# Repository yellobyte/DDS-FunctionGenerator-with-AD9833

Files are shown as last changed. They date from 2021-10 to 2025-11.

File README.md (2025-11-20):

# DDS Function Generator with AD9833 module #

While doing some work on Audio Amplifiers and Light Organs in 2016 I needed a simple (and not necessarily absolutely precise) **Function Generator** to generate sinus signals in the frequency range of 10Hz...30kHz and voltage levels of about 0.7...1Vrms. All devices I needed to test had input impedances in the range of ~2kOhm...20kOhm. 
  
Unfortunately I didn't call a function generator my own. So in order to have some additional fun, putting together one by myself instead of buying one on the internet was the only option. I ended up with a device able to generate output signals with the following specifications:

 - **Sinus/Triangle, amplitude 0.01 to 6.00 Vpp, frequency 1Hz to 500kHz**
 - **TTL, amplitude 5 Vpp, frequency 1Hz to 5.0 MHz**
 
 Switching waveform, output level and frequency is done with 2 front panel knobs: a pushbutton switch labelled "Select" and a simple rotary encoder with push switch labelled "Modify". The display is a standard 16x2 LCD (HD44780) having a small I2C-LCD adapter module (PCF8574 I/O expander) mounted piggyback.

All components were put into an enclosure UM 52011-L from [Bopla](https://www.bopla.de/en/enclosure-technology/product/ultramas/enclosure-with-air-vents/um-52011-l.html) which had exactly the size needed.
  
### Front side with 2 controls, 16x2 LCD display and BNC output socket: ###
  
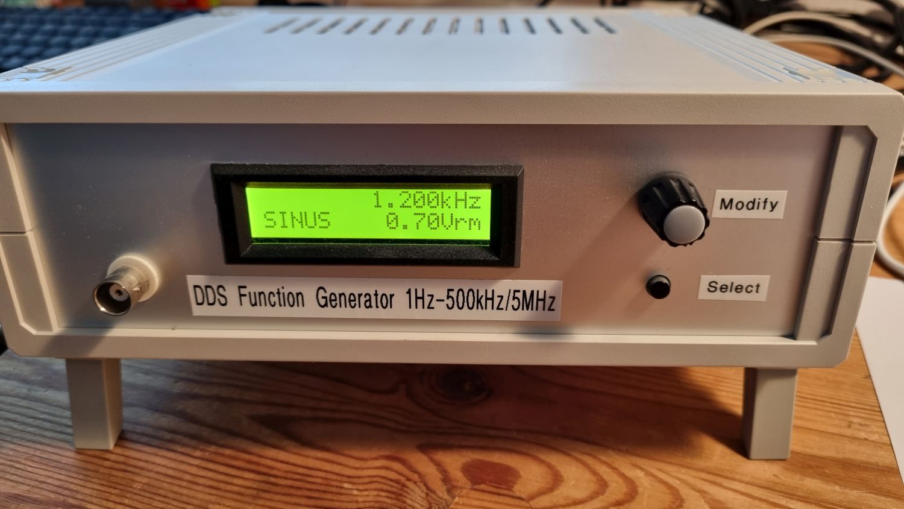
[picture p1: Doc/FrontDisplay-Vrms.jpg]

  
The two controls allow to change signal [waveform](https://github.com/yellobyte/DDS-FunctionGenerator-with-AD9833/raw/main/Doc/SettingWaveform.mp4), output [level](https://github.com/yellobyte/DDS-FunctionGenerator-with-AD9833/raw/main/Doc/SettingLevel+SwitchingBetweenVppVrms.mp4) (Vpp resp. Vrms for sinus/triangle) and [frequency](https://github.com/yellobyte/DDS-FunctionGenerator-with-AD9833/raw/main/Doc/SettingFrequency.mp4) very quickly. Have a look at folder [**Doc**](https://github.com/yellobyte/DDS-FunctionGenerator-with-AD9833/blob/main/Doc) to find more details. 
  
## General technical info ##

The analog part of the circuitry is shielded in tin plate (an old coffee tin proved ideal for this purpose, you will recognize my favorite Italian coffee brand) to keep the output signal as clear as possible and reduce EMI. 
  
The settings for waveform/level/frequency get stored in EEPROM of the Atmega168A and therefore stay permanent even after switching the device off/on.

By default, turning the encoder knob will change the output signal immediately. For example, changing the output level from 0.5Vpp up to 6.00Vpp requires a few full turns of the knob and therefore will take a few seconds. Means the output level will rise steadily.
  
However, sometimes, when testing the automatic gain control (AGC) of audio input stages for example, it requires a signal that rises instantaneously . No problem! Switch off the device and have the encoder knob pressed for two seconds while switching power back on. After that, changing a single setting (waveform, level or frequency) on the display will not affect the output signal. Only after pressing the knob shortly (<0.5s) will the new setting appear at the output.
    
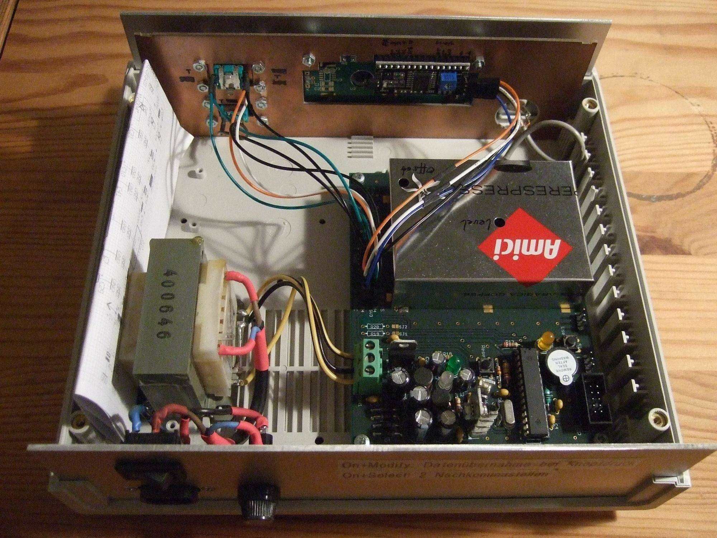
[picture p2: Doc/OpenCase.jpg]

  
### Some circuit details ###
    
The DDS module (available for only a few dollars on Ebay/Ali/etc.) uses a sophisticated programmable waveform generator IC [AD9833](https://www.analog.com/en/products/ad9833.html) with 0...12.5MHz output frequency rate. 
  
Unfortunately the output pin of the AD9833 chip on the small **DDS module** shipped from Asia was galvanically isolated from the modules output pin (due to C8/C9). The quickest remedy was to bridge one of the two capacitors with a short wire, as you can see on the [**board**](https://github.com/yellobyte/DDS-FunctionGenerator-with-AD9833/raw/main/Doc/Board_V1.0_top.jpg) or below in the modules schematic. Apart from that the module was perfect for the task.

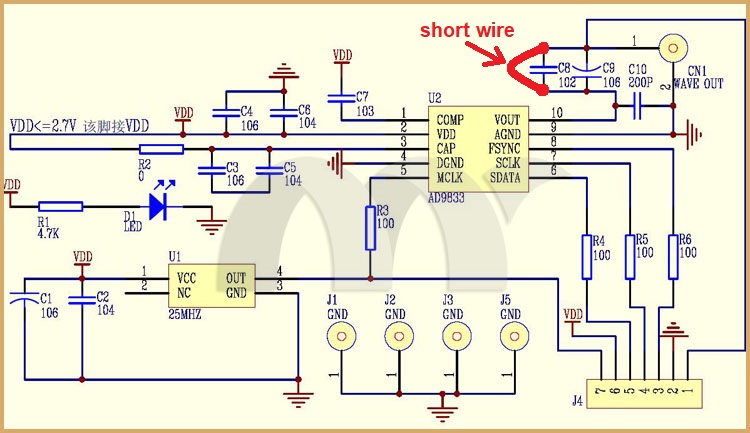
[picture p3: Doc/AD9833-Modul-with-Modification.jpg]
  

The AD9833 is written to via SPI interface. The internet provides ready to use libraries for it but I decided to use some small, quick and dirty code for only two features are needed: setting frequency & waveform.
  
The output signal of the AD9833 is unipolar and has a constant amplitude  of +38mV...+650mV over the full frequency range. The combination of Opamps IC3 + IC5 converts it to a bipolar, symmetrical signal with constant amplitude +/- 3.0V (6Vpp).  

The combination DAC1/IC6/IC7 is then used to attenuate this signal to the desired output level. The DAC IC [AD5452](https://www.analog.com/en/products/ad5452.html) contains a 12-bit R-2R-ladder and simply sets the amplification factor (better to say attenuation factor) of the combination IC6 (Opamp) + IC7 (unity gain buffer). To set the output level the selected value (0.01...6.00Vpp resp. its equivalent in Vrms) gets translated into a 12-bit value (range 0...4095) and then written to the DAC via SPI bus.

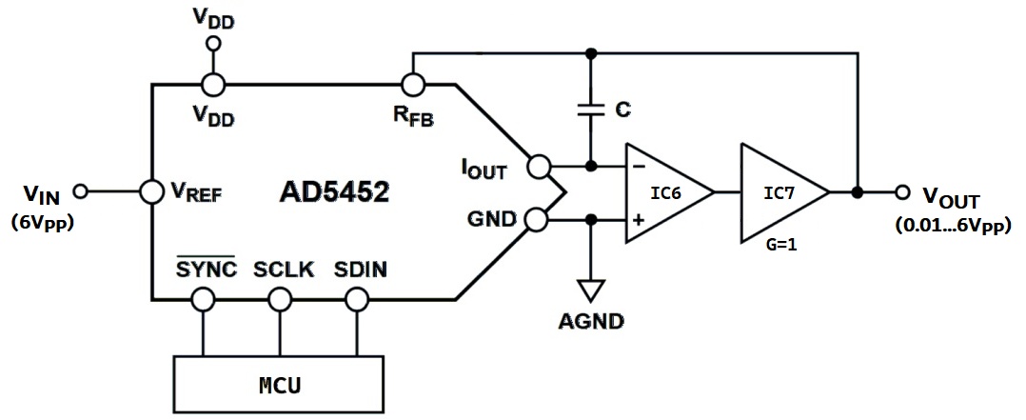
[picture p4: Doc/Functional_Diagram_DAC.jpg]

  
The [LMH6321](https://www.ti.com/product/LMH6321) (IC7) acts as output driver/buffer with gain=1 (unity gain) and features an  "adjustable current limit". Resistor R16 sets this limit to roughly 110mA for thermal protection in case of a short at the BNC output socket.
  
Capacitors C20/C22/C38 are not populated because the Opamp [NE5534](https://www.ti.com/product/NE5534) (IC6) showed sufficient results without them. In case you want to increase the maximum analog output frequency and try different Opamps for best results you might need them.

The two 100 Ohm resistors R9/R14 in parallel at the IC7 driver output were designed into the schematic and soldered on the board but shorted with wire in the end because the device will solely get connected to audio devices with a few 1..10kOhm input impedance and only generates audio resp. low analog frequency signals anyway. Means it will never produce RF signals, see low impedance loads, mismatches, reflections and other effects of RF hell. BTW: Having those two resistors in parallel and feeding devices with very low input impedance, e.g. 50 Ohm, would in this case halve the usable signal amplitude and subsequently force you to correct the displayed signal level on LCD, etc. Things would get complicated. 
  
Therefore wiring the IC7 driver output directly to CON2 (connected to BNC output socket) gives the function generator a very low output impedance and is appropriate under these circumstances. 

The rotary encoders two outer pins go to IMPULS-A/IMPULS-B and the middle one to ground GND. It's two switch pins go to IMPULS-SW and GND. The two pins of the separate "Select" switch go to SELECT-SW and GND on the board.  

The four pins of socket "LCD 16x2" go to the matching pins on the small **I2C-LCD board** that is mounted piggyback on the 16x2 LCD front display.
  
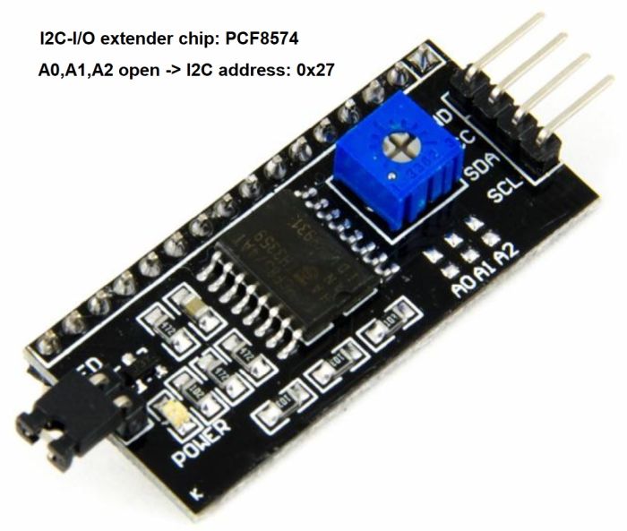
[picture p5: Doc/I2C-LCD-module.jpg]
  

The logic gate IC8D is a low-power-Schottky Schmitt-Trigger-Inverter [74LS14](https://www.ti.com/product/SN74LS14) which acts as buffer between DDS chip and BNC output socket when a TTL output signal is selected. Firstly, its TTL signal is slightly better than the one generated by the AD9833 and secondly, a permanent short at the output would only destroy this socketed, easy replacable and inexpensive chip and not the tiny DDS chip (AD9833 in a MSOP package) soldered on the DDS module.
  
The whole device is powered by a standard 230V(prim)/2x6V(sec)/12VA transformer attached to CON1. Two jellybean voltage regulator ICs (IC2/7805 and IC4/7905) provide the needed positive/negative voltages.
  
The firmware for the device was done with VSCode/PlatformIO and is located in folder [**Software**](https://github.com/yellobyte/DDS-FunctionGenerator-with-AD9833/blob/main/Software) together with all needed fuse settings. For programming the Atmega168A I used this in-circuit [**Programmer**](https://github.com/yellobyte/USB-Atmel-In-Circuit-Programmer), connected to the 10-pin ISP socket.
  
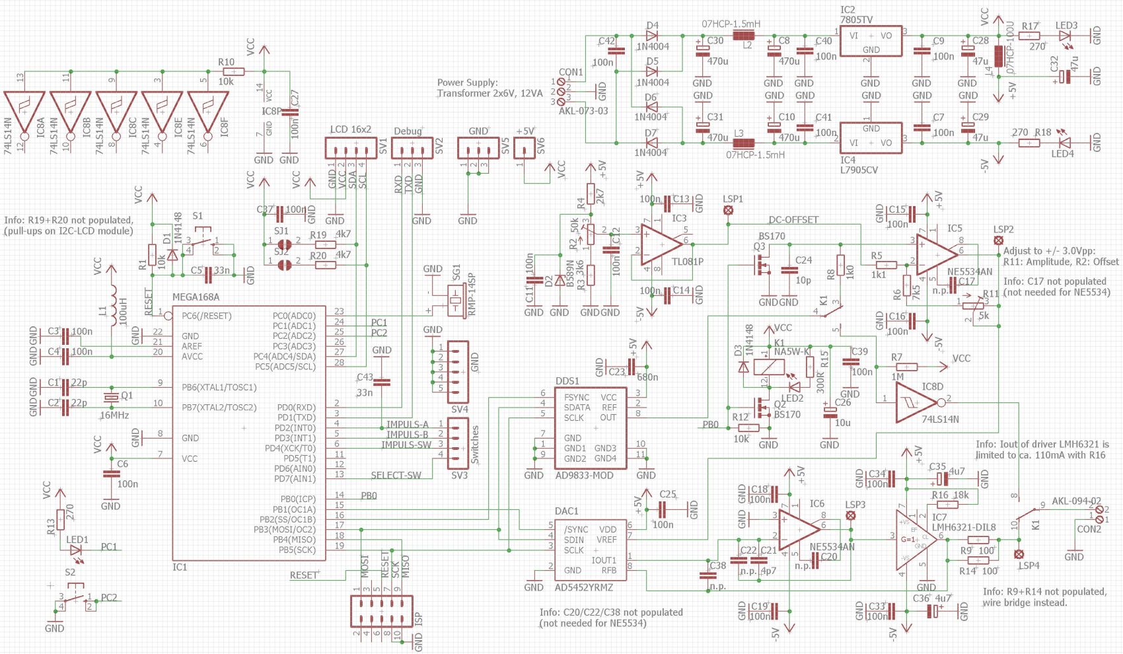
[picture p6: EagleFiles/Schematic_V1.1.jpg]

  
### Adjusting procedure ###

For properly adjusting the analog part an oscilloscope connected to output (BNC socket) is recommended/needed. Trimmer R11 sets the maximum amplitude and trimmer R2 adjusts the offset for getting a symmetrical signal.
  
First set the output signal to Sinus, 1.000kHz and 6.00Vpp using the knobs. Then adjust the analog output signal with the two trimmers as shown below. If your osci can display Cmean, have an eye on it. Try to get it to +/-0V as close as possible for a nice symmetrical output signal without offset.

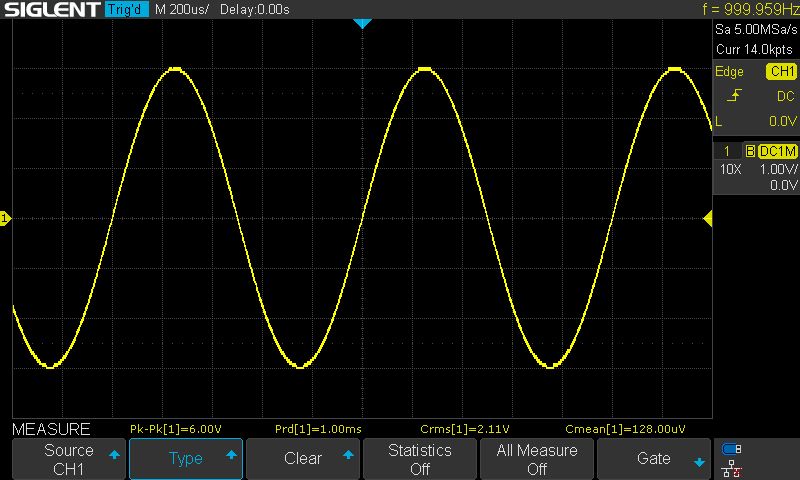
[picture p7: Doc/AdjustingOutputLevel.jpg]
 

## Eagle Schematic and PCB Files ##

All relevant Eagle files (schematic, board and Gerber production files Rev 1.1) are located in folder [**EagleFiles**](https://github.com/yellobyte/DDS-FunctionGenerator-with-AD9833/blob/main/EagleFiles). The necessary Gerber files for production are zipped into file "FG with AD9833.zip".  

The pictures in folder [**Doc**](https://github.com/yellobyte/DDS-FunctionGenerator-with-AD9833/blob/main/Doc) still show board revision 1.0.   Revision 1.1 is almost identical and contains only cosmetic changes.

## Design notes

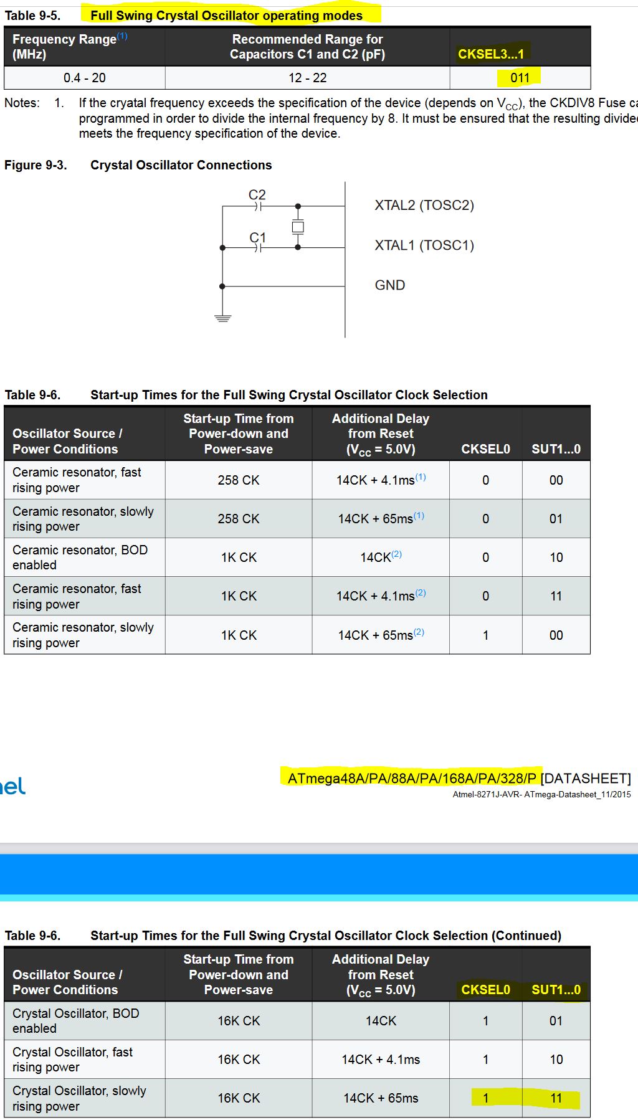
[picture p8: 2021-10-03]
Software/Low-Fuse-Spec2.JPG

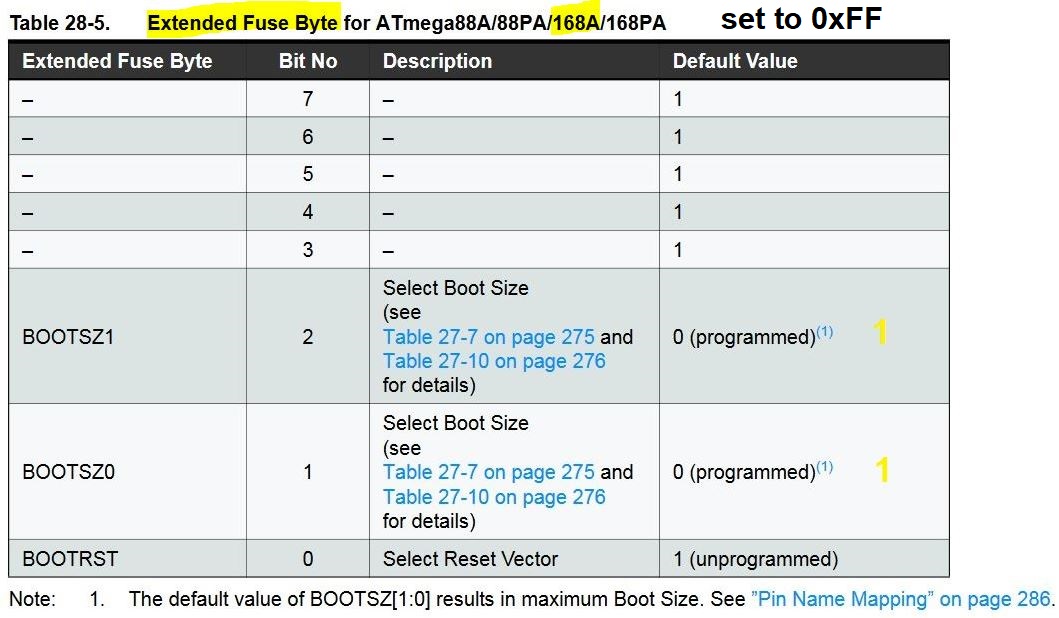
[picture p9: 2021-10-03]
Software/Extended-Fuse-Spec1.JPG

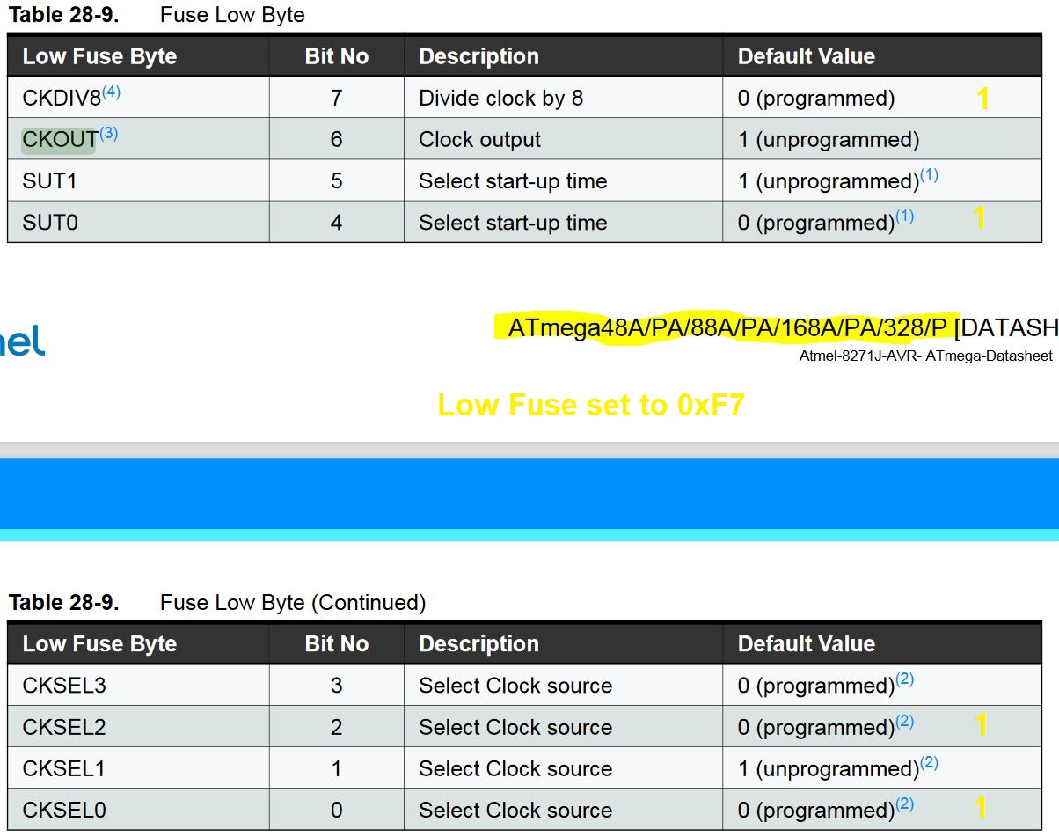
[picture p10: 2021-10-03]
Software/Low-Fuse-Spec1.JPG

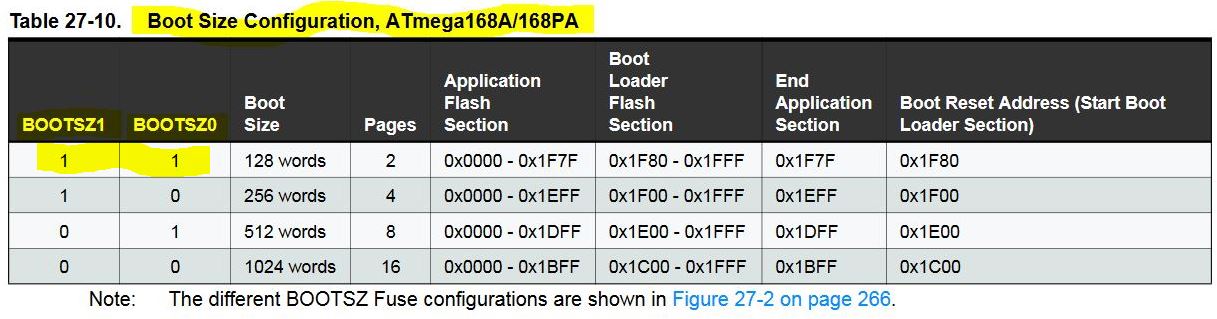
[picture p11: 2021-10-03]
Software/Extended-Fuse-Spec2.JPG

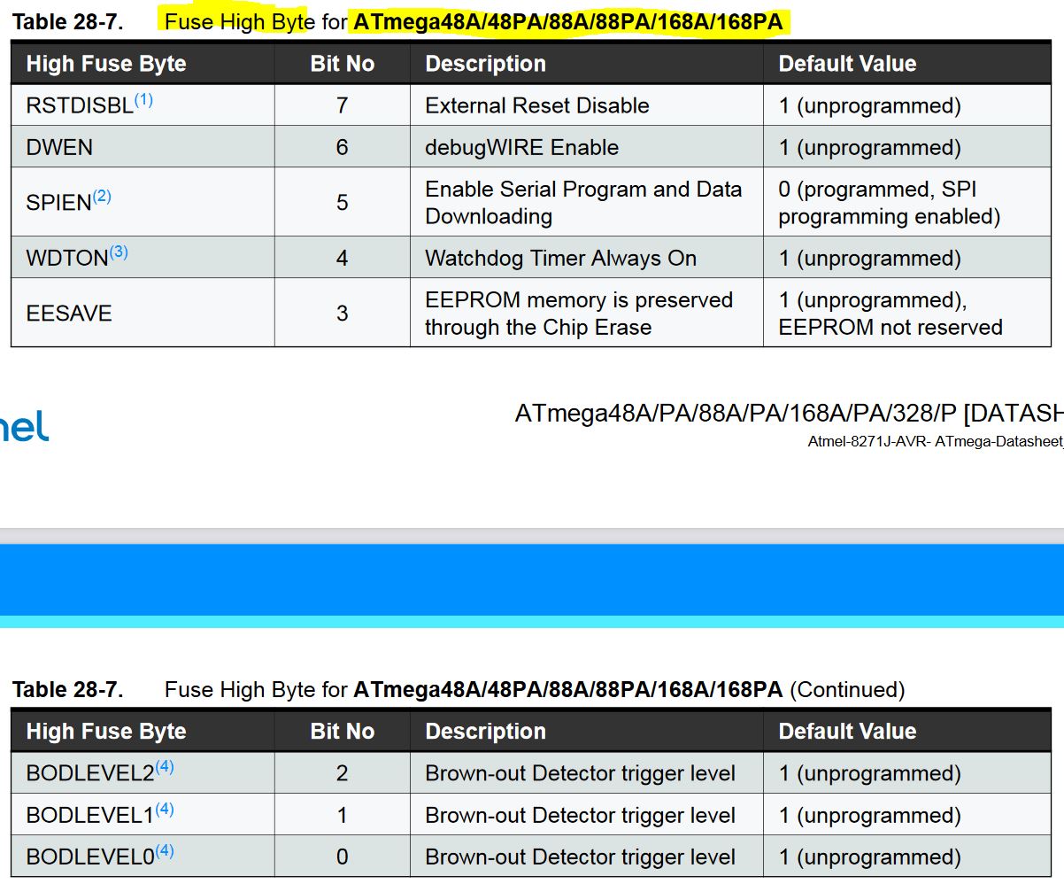
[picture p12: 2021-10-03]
Software/High-Fuse-Spec.JPG

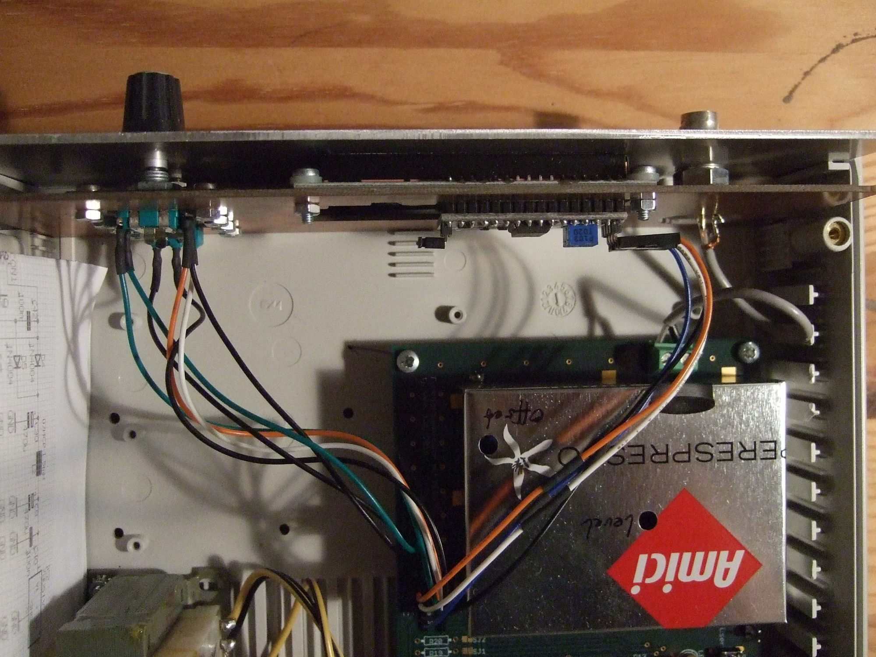
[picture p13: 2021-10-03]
Doc/FrontModule.JPG

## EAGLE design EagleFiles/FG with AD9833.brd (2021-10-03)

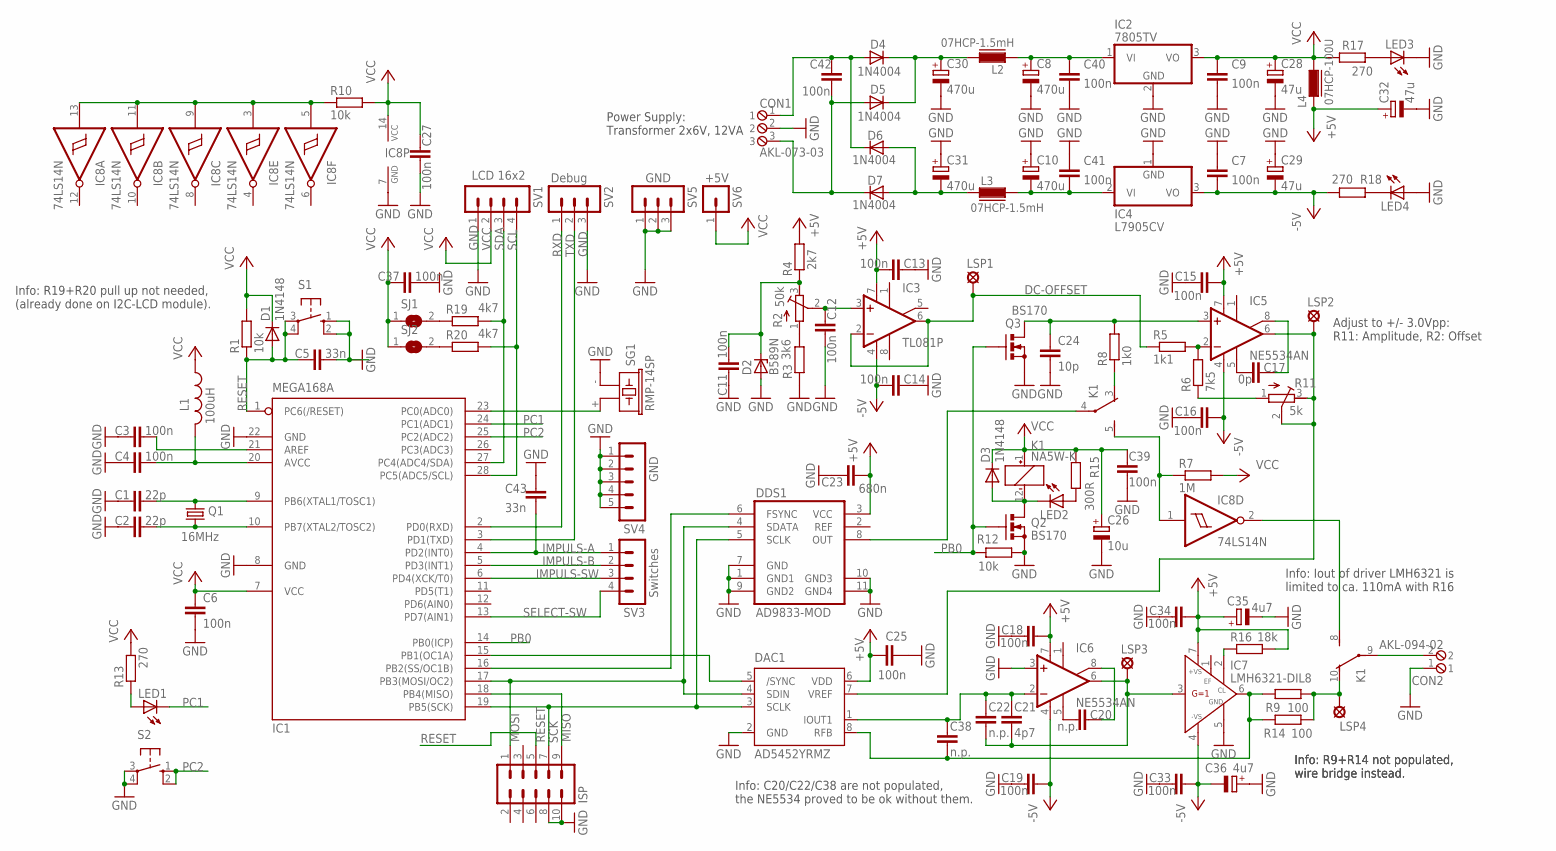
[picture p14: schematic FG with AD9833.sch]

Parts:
C1, C2: 22p; C025-024X044
C3, C4, C6, C7, C9, C11, C12, C13, C14, C15, C16, C18, C19, C25, C27, C33, C34, C37, C39, C40, C41, C42: 100n; C050-024X044
C5: 33n; C025-024X044
C8, C10, C30, C31: 470u; E3,5-8
C17: 0p; C025-024X044
C20, C22, C38: n.p.; C025-024X044
C21: 4p7; C025-024X044
C23: 680n; C050-024X044
C24: 10p; C025-024X044
C26: 10u; TT2D4
C28, C29, C32: 47u; E2,5-6
C35, C36: 4u7; TT2D4
C43: 33n; C050-024X044
CON1: AKL-073-03
CON2: AKL-094-02
D1: 1N4148; DO35-10
D2: B589N; TO-92H
D3: 1N4148; DO35-7
D4, D5, D6, D7: 1N4004; DO41-10
DAC1: AD5452YRMZ; MSOP08
DDS1: AD9833-MOD
IC1: MEGA168A; DIL28-3
IC2: 7805TV; TO220V
IC3: TL081P; DIL08
IC4: L7905CV; TO220-V
IC5, IC6: NE5534AN; DIL08
IC7: LMH6321-DIL8; DIL08-ADAP
IC8: 74LS14N; DIL14
ISP: ML10
K1: NA5W-K; HX
L1: 100uH; 0207/10
L2, L3: 07HCP-1.5mH; FASTRON_07HCP_INDUCTOR
L4: 07HCP-100U; FASTRON_07HCP_INDUCTOR
LED1, LED2, LED3, LED4: LED5MM
LSP1, LSP2, LSP3, LSP4: LSP11
Q1: 16MHz; HC49/S
Q2, Q3: BS170; SOT54E
R1, R10, R12: 10k; 0207/10
R2: 50k; RTRIM64W
R3: 3k6; 0207/10
R4: 2k7; 0207/10
R5: 1k1; 0207/10
R6: 7k5; 0207/10
R7: 1M; 0207/10
R8: 1k0; 0207/10
R9, R14: 100; 0207/10
R11: 5k; RTRIM64W
R13, R17, R18: 270; 0207/10
R15: 300R; 0207/10
R16: 18k; 0207/10
R19, R20: 4k7; 0207/10
S1, S2: 10-XX; B3F-10XX
SG1: RMP-14SP; F/CM12P
SJ1, SJ2: SJ
SV1, SV3: MA04-1
SV2, SV5: MA03-1
SV4: MA05-1
SV6: MA01-1

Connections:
+5V: C13.2, C15.2, C18.2, C23.2, C25.1, C32.+, C34.2, C35.+, DAC1.6 (VDD), DDS1.3 (VCC), IC3.7 (V+), IC5.7 (V+), IC6.7 (V+), IC7.7 (+VS), L4.1, R4.2, R16.2
-5V: C7.2, C14.2, C16.2, C19.2, C29.-, C33.2, C36.-, IC3.4 (V-), IC4.3 (VO), IC5.4 (V-), IC6.4 (V-), IC7.4 (-VS), R18.1
AREF: C3.2, IC1.21 (AREF)
AVCC: C4.2, IC1.20 (AVCC), L1.2
DC-OFFSET: IC3.2 (-IN), IC3.6 (OUT), LSP1.MP, R5.1
GND: C1.1, C2.1, C3.1, C4.1, C5.2, C6.2, C7.1, C8.-, C9.2, C10.+, C11.1, C12.2, C13.1, C14.1, C15.1, C16.1, C18.1, C19.1, C23.1, C24.2, C25.2, C26.-, C27.2, C28.-, C29.+, C30.-, C31.+, C32.-, C33.1, C34.1, C35.-, C36.+, C37.2, C39.1, C40.2, C41.1, C43.1, CON1.2, CON2.1, D2.2 (A), DAC1.2 (GND), DDS1.1 (GND1), DDS1.7 (GND), DDS1.9 (GND2), DDS1.10 (GND3), DDS1.11 (GND4), IC1.8 (GND), IC1.22 (GND), IC2.2 (GND), IC4.1 (GND), IC6.3 (+IN), IC7.5 (GND), IC8.7 (GND), ISP.8, ISP.10, LED3.K (C), LED4.A, Q2.S, Q3.S, R3.1, R12.1, S1.1 (S), S1.2 (S1), S2.3, S2.4 (P1), SG1.- (2), SV1.1, SV2.3, SV4.1, SV4.2, SV4.3, SV4.4, SV4.5, SV5.1, SV5.2, SV5.3
IMPULS-A: C43.2, IC1.4 (PD2(INT0)), SV3.1
IMPULS-B: IC1.5 (PD3(INT1)), SV3.2
IMPULS-SW: IC1.6 (PD4(XCK/T0)), SV3.3
MISO: IC1.18 (PB4(MISO)), ISP.9
MOSI: DAC1.4 (SDIN), DDS1.4 (SDATA), IC1.17 (PB3(MOSI/OC2)), ISP.1
unnamed: R2.1 (A), R3.2
unnamed: DDS1.6 (FSYNC), IC1.16 (PB2(SS/OC1B))
unnamed: DAC1.5 (/SYNC), IC1.15 (PB1(OC1A))
unnamed: IC5.2 (-IN), R5.2, R6.2
unnamed: C8.+, C40.1, IC2.1 (VI), L2.1
unnamed: IC8.1 (I), K1.5 (S), R7.1
unnamed: C31.-, D6.A, D7.A, L3.1
unnamed: DDS1.8 (OUT), K1.4
unnamed: C17.1, IC5.5 (CMP)
unnamed: C17.2, IC5.8 (ON/CMP)
unnamed: K1.3 (O), R8.1
unnamed: R6.1, R11.1 (A)
unnamed: LED1.A, R13.1
unnamed: C30.+, D4.C, D5.C, L2.2
unnamed: C10.-, C41.2, IC4.2 (VI), L3.2
unnamed: C42.1, CON1.1, D4.A, D6.C
unnamed: C21.2, C22.2, IC6.6 (OUT), IC7.3 (IN), LSP3.MP
unnamed: IC1.23 (PC0(ADC0)), SG1.+ (1)
unnamed: C42.2, CON1.3, D5.A, D7.C
unnamed: IC8.3 (I), IC8.5 (I), IC8.9 (I), IC8.11 (I), IC8.13 (I), R10.1
unnamed: IC7.2 (CL), R16.1
unnamed: C38.2, DAC1.8 (RFB), IC7.6 (OUT), R9.2, R14.2
unnamed: K1.10 (O), LSP4.MP, R9.1, R14.1
unnamed: LED3.A, R17.1
unnamed: LED4.K (C), R18.2
unnamed: C20.1, IC6.5 (CMP)
unnamed: R19.1, SJ1.2
unnamed: C20.2, IC6.8 (ON/CMP)
unnamed: C21.1, C22.1, C38.1, DAC1.1 (IOUT1), IC6.2 (-IN)
unnamed: R20.1, SJ2.2
unnamed: CON2.2, K1.9
unnamed: C24.1, IC5.3 (+IN), Q3.D, R8.2
unnamed: C12.1, IC3.3 (+IN), R2.2 (S)
unnamed: C11.2, D2.1 (C), R2.3 (E), R4.1
unnamed: D3.A, K1.12 (-), LED2.K (C), Q2.D
unnamed: IC8.2 (O), K1.8 (S)
unnamed: LED2.A, R15.2
OSC1: C1.2, IC1.9 (PB6(XTAL1/TOSC1)), Q1.2
OSC2: C2.2, IC1.10 (PB7(XTAL2/TOSC2)), Q1.1
PB0: IC1.14 (PB0(ICP)), Q2.G, Q3.G, R12.2
PC1: IC1.24 (PC1(ADC1)), LED1.K (C)
PC2: IC1.25 (PC2(ADC2)), S2.1 (S), S2.2 (S1)
RESET: C5.1, D1.A, IC1.1 (PC6(/RESET)), ISP.5, R1.1, S1.3, S1.4 (P1)
RXD: IC1.2 (PD0(RXD)), SV2.1
SCK: DAC1.3 (SCLK), DDS1.5 (SCLK), IC1.19 (PB5(SCK)), ISP.7
SCL: IC1.28 (PC5(ADC5/SCL)), R20.2, SV1.4
SDA: IC1.27 (PC4(ADC4/SDA)), R19.2, SV1.3
SELECT-SW: IC1.13 (PD7(AIN1)), SV3.4
TXD: IC1.3 (PD1(TXD)), SV2.2
VCC: C6.1, C9.1, C26.+, C27.1, C28.+, C37.1, C39.2, D1.C, D3.C, IC1.7 (VCC), IC2.3 (VO), IC8.14 (VCC), K1.1 (+), L1.1, L4.2, R1.2, R7.2, R10.2, R13.2, R15.1, R17.2, SJ1.1, SJ2.1, SV1.2, SV6.1
VREF: DAC1.7 (VREF), IC5.6 (OUT), LSP2.MP, R11.2 (S), R11.3 (E)

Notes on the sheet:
LCD 16x2
Switches
GND
Debug
Info: R19+R20 pull up not needed, (already done on I2C-LCD module).
+5V
Adjust to +/- 3.0Vpp: R11: Amplitude, R2: Offset
Info: R9+R14 not populated, wire bridge instead.
Power Supply: Transformer 2x6V, 12VA
Info: C20/C22/C38 are not populated, the NE5534 proved to be ok without them.
Info: Iout of driver LMH6321 is limited to ca. 110mA with R16

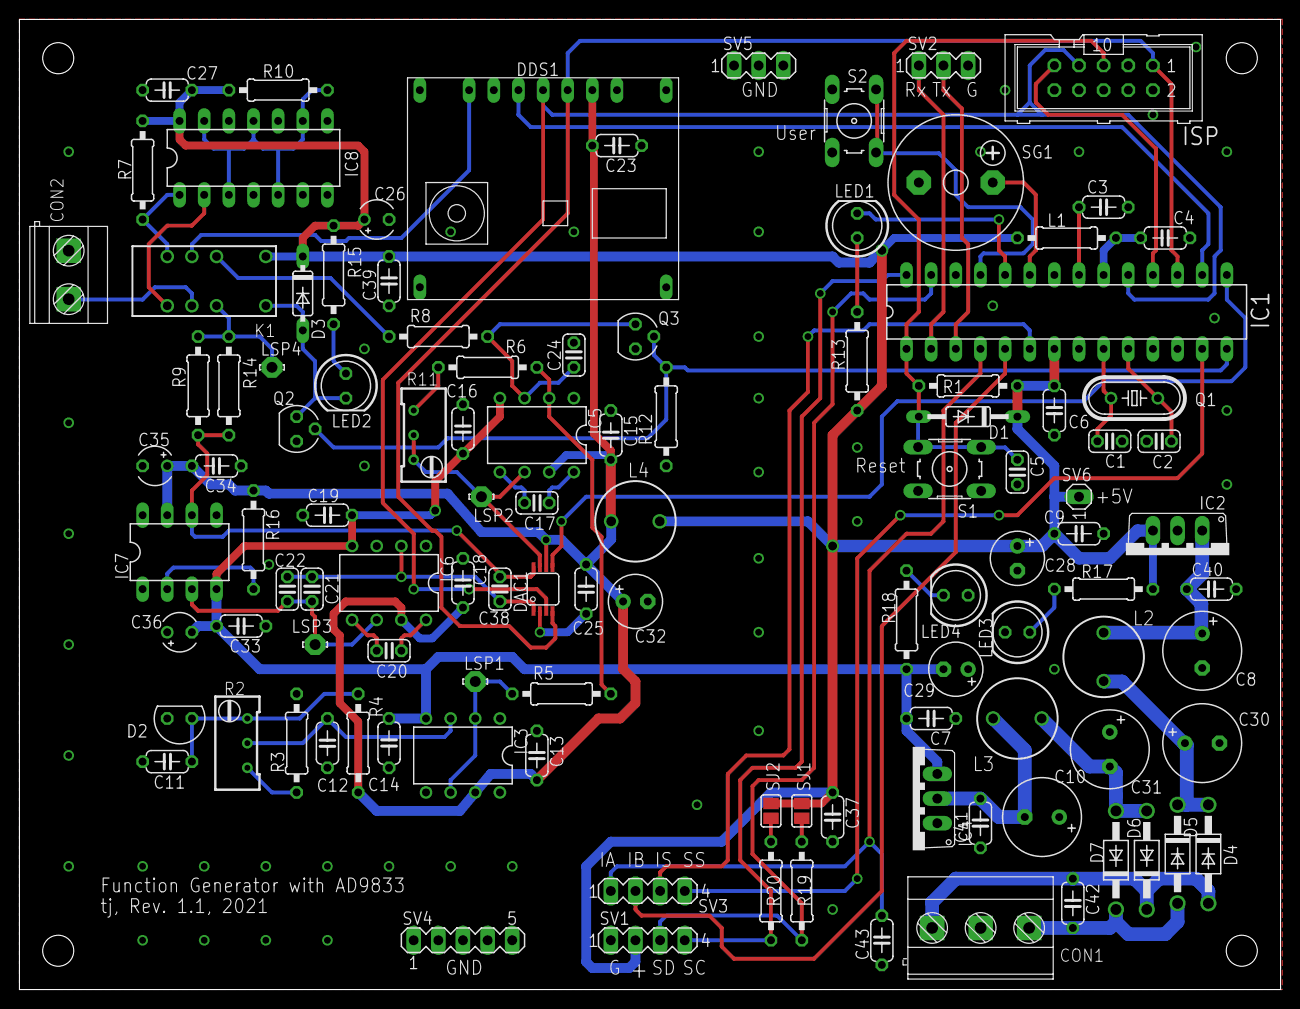
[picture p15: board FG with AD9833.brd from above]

Board: 2 copper layers, 130.0 x 100.0 mm, 110 parts (0 on the bottom side), 62 nets.

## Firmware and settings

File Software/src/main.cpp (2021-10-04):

/******************************************************************************

  Function generator based on a China AD9833 DDS module, controlled by an Atmega168
  
  Info:
    If the encoder button is pressed during power on then you always have to press 
    this button to activate new values. A short beep will confirm that. 
    The displayed output level represents Vpp or Vrms, this is changeable with
    the encoder button by a long press (>0.5s in output level changing mode).

  Created: August 2016
  Changes: 2020/09/05 usage of lib LiquidCrystal_I2C instead of own quick and dirty code
           2021/10/01 possibility to set output level in Vrms added
           2021/10/02 watchdog added
  Author: ThJ <yellobyte@bluewin.ch>

******************************************************************************/

#include <Arduino.h>
#include <SPI.h>
#include <Wire.h> 
#include <LiquidCrystal_I2C.h>
#include <avr/wdt.h> 
#include "ad9833.h"
#include "external.h"

#define USE_WDT           // uncomment for using watchdog
//#define USE_SERIAL        // uncomment for using serial output

// some configurable definitions
#define MAX_IDLE_TIME 30      // 30 sec
#define MAX_FREQ      500000  // 500kHz for sinus/triangle
#define MAX_FREQ_TTL  5000000 // 5.0MHz for TTL

#define OUTPUT_WAVEFORM_DEFAULT   SINUS
#define OUTPUT_LEVEL_MODE_DEFAULT V_P2P   // Vpp
#define OUTPUT_LEVEL_DEFAULT      200     // 2.0Vpp
#define OUTPUT_FREQU_DEFAULT      1000    // 1kHz

#define V_STEPSIZE_SMALL 1    // useful values are only 1,2 or 5

// fix definitions - don't change
#define I_NORMAL      0       // immediate activation of new values without pushing the turn-push-button
#define I_EXPLICIT    1       // activation of new values requires pushing the turn-push-button
#define V_STEPSIZE_10 10

// state machine states
#define	M_IDLE        0
#define M_WAVEFORM    1
#define M_LEVEL       2
#define M_FREQUENCY1  3
#define M_FREQUENCY2  4

//
// global variables (set to default if required)
//
uint16_t outputLevelMaxVrms = (OUTPUT_WAVEFORM_DEFAULT == SINUS) ? V_RMS_MAX_SIN : V_RMS_MAX_TRI;
uint16_t outputLevelMinVrms = (OUTPUT_WAVEFORM_DEFAULT == SINUS) ? V_RMS_MIN_SIN : V_RMS_MIN_TRI;
uint8_t	 outputWaveform = OUTPUT_WAVEFORM_DEFAULT;
uint16_t outputLevel = OUTPUT_LEVEL_DEFAULT;          // the chosen output level
uint8_t  outputLevelMode = OUTPUT_LEVEL_MODE_DEFAULT; // defines what above value represents (Vpp or Vrms)
uint32_t outputFrequency = OUTPUT_FREQU_DEFAULT;
uint8_t	 systemState	= M_IDLE;
uint8_t  tempWaveform = OUTPUT_WAVEFORM_DEFAULT;
uint16_t tempLevel = OUTPUT_LEVEL_DEFAULT;
uint32_t tempFrequency = OUTPUT_FREQU_DEFAULT;
uint32_t tempDigit = OUTPUT_FREQU_DEFAULT;
int8_t   ret = 0;
int32_t  temp = 0;
buttonEvent event;

extern volatile uint8_t rotaryImpulseLeft;
extern volatile uint8_t rotaryImpulseRight;

volatile uint8_t systemIdleTime = 0;
volatile uint8_t timer2 = 0;

uint8_t outputLevelStepSize = V_STEPSIZE_SMALL;
uint8_t inputMode = I_NORMAL;

// for remembering settings after power off
uint8_t	 EEMEM eWaveform;
uint16_t EEMEM eLevel;
uint8_t  EEMEM eLevelMode;
uint32_t EEMEM eFrequency;

LiquidCrystal_I2C lcd(0x27,16,2); // set the LCD I2C address, 16 cols, 2 rows

#ifdef USE_WDT
//ISR (WDT_vect) {}               // could be used instead of a default WDT reset (power reset)
#endif

//
// macros & ISR function for hardware timer 2 of Atmega328
// (8-bit Timer 2 with base clock 15625Hz (F_CPU/1024): overflow every 1/61s=~16ms)
//
#define Timer2Init() {\
  TCCR2B |= (1<<CS22) | (1<<CS21) |(1<<CS20);\
}

// enable timer 2 overflow interrupt (start timer 2)
#define Timer2Start() {\
  timer2 = 0;\
  systemIdleTime = 0;\
  TIMSK2 |= (1<<TOIE2);\
}

// disable timer 2 interrupt (stop timer 2)
#define Timer2Stop() {\
  TIMSK2 &= (~(1<<TOIE2));\
}

// re-start timer 2
#define Timer2Clear() {\
  timer2 = 0;\
  systemIdleTime = 0;\
}

// timer 2 overflow interrupt routine
ISR(TIMER2_OVF_vect){
  if (timer2++ > 60) {            // ca. 1 sec over ?
    timer2 = 0;
    systemIdleTime++;
  }
}

//
// some function definitions
//
static void SPIInit(void)
{
  digitalWrite(PIN_PB1, HIGH);    // chip select signal for DAC AD5452 set high
  pinMode(PIN_PB1, OUTPUT);       // chip select port for DAC AD5452 set to output
  SPI.begin();                    // SPI SS pin is CS signal for AD9833, will be high
}

static void setAndStoreOutputLevel()
{
  EXTDacSetLevel(outputLevel, outputWaveform, outputLevelMode);
  eeprom_busy_wait();
  eeprom_update_word(&eLevel,outputLevel);
}

static void setAndStoreOutputFrequency()
{
  DDSFreq(outputFrequency);
  eeprom_busy_wait();
  eeprom_update_dword(&eFrequency,outputFrequency);
}            

//
// runs once after power on
//
void setup() {
  // put your setup code here, to run once:
#ifdef USE_SERIAL
  Serial.begin(38400);
#endif

  EXTSelectSwitchInit();
  EXTRotaryInit();
  if (EXTRotaryButtonCheck()) {
    // encoder button was pressed during power on
    inputMode = I_EXPLICIT;
  }

  // read stored parameters from EEPROM and check validity
  eeprom_busy_wait();
  outputWaveform = eeprom_read_byte(&eWaveform);
  if (outputWaveform != SINUS && outputWaveform != TRIANGLE && outputWaveform != SQUARE) {
    outputWaveform = SINUS;
  }
  eeprom_busy_wait();
  outputFrequency = eeprom_read_dword(&eFrequency);
  if (outputFrequency < 1 || outputFrequency > ((outputWaveform == SQUARE) ? MAX_FREQ_TTL : MAX_FREQ)) {
    outputFrequency = OUTPUT_FREQU_DEFAULT;
  }
  eeprom_busy_wait();
  outputLevel = eeprom_read_word(&eLevel);
  if (/*outputLevel < 10 || */outputLevel > OUTPUT_LEVEL_VPP_MAX) {
    // set default output level
    outputLevel = OUTPUT_LEVEL_DEFAULT;
  }
  if (outputLevelStepSize == V_STEPSIZE_10) {		
    // fix level matching step size if necessary (e.g. 105 -> 100)
    outputLevel /= 10;
    outputLevel *= 10;
  }
  eeprom_busy_wait();
  outputLevelMode = eeprom_read_byte(&eLevelMode);
  if (outputLevelMode != V_RMS && outputLevelMode != V_P2P) {
    // set default output level mode
    outputLevelMode = OUTPUT_LEVEL_MODE_DEFAULT;
  }

  // Initialize LCD module, Cursor not visible
  lcd.init();
  lcd.backlight();

  // Power on message
  lcd.print("DDS Function Ge-");
  lcd.setCursor(0,1);                           // go to the next line
  lcd.print("nerator (AD9833)");
  delay(2500);

  // Display frequency range
  lcd.clear();
  lcd.print("Range:1Hz-0.5MHz");
  lcd.setCursor(0,1);
  lcd.print("TTL:  1Hz-5.0MHz");
  lcd.noCursor();
  delay(2500);

   // If button press needed to activate new values then give info
  if (inputMode == I_EXPLICIT) {
    lcd.clear();
    lcd.print("Pressing button ");
    lcd.setCursor(0,1);
    lcd.print("changes value!");
    lcd.noCursor();
    delay(2500);
  }

  // set display to default
  lcd.clear();
  lcd.noCursor();

  SPIInit();
  EXTRelaisInit();
  EXTBuzzerInit();
  EXTDacInit();
  DDSInit();
  Timer2Init();
  
  EXTDacSetLevel(outputLevel, outputWaveform, outputLevelMode);
  EXTDisplayFrequency(outputFrequency,0);
  EXTDisplayWaveform(outputWaveform);
  if (outputWaveform != SQUARE) {
    EXTDisplayLevel(outputLevel, outputLevelMode);
    EXTRelaisOnOff(RELAIS_OFF);
  }
  else {
    EXTRelaisOnOff(RELAIS_ON);
    delay(10);
  }

  DDSFreq(outputFrequency);
  //delay(1);
  DDSSignal(outputWaveform); 

#ifdef USE_WDT
  wdt_enable(WDTO_4S);                          // Enable Watchdog (4 sek.)
  wdt_reset();
#endif
  //sei();                                      // enable global interrupts - done in framework
#ifdef USE_SERIAL
  Serial.println(F("Programmstart ok."));  
#endif
}

void loop() {
  // put your main code here, to run repeatedly:
#ifdef USE_WDT
  wdt_reset();                                  // reset watchdog
#endif  
  if (systemState == M_IDLE) {
    // we are idle and only check select switch
    if (EXTSelectSwitchCheck()) {
      systemState = M_WAVEFORM;
      rotaryImpulseLeft = rotaryImpulseRight = 0;
      tempWaveform = outputWaveform;
      lcd.setCursor(0,1);
      lcd.blink();
      Timer2Start();
    }
  }
  else if (systemState == M_WAVEFORM) {
    // selecting waveform
    if (systemIdleTime >= MAX_IDLE_TIME) {
      systemState = M_IDLE;
      Timer2Stop();
      lcd.noCursor();
      if (tempWaveform != outputWaveform) EXTDisplayWaveform(outputWaveform);	
      if (outputWaveform != SQUARE ) EXTDisplayLevel(outputLevel, outputLevelMode);
    }
    else if ((ret = EXTRotaryImpulseCheck()) != 0) {
      Timer2Clear();
      if (ret == -1) {
        switch (tempWaveform) {
          case SINUS:	tempWaveform = SQUARE; break;
          case SQUARE: tempWaveform = TRIANGLE; break;
          default: tempWaveform = SINUS; break;
        }
      }
      else {
        switch (tempWaveform) {
          case SINUS:	tempWaveform = TRIANGLE; break;
          case TRIANGLE: tempWaveform = SQUARE; break;
          default: tempWaveform = SINUS; break;
        }
      }
      if (inputMode == I_NORMAL) {
        goto JUMP1;
      }
      else {
        EXTDisplayWaveform(tempWaveform);
        if (tempWaveform != SQUARE) EXTDisplayLevel(outputLevel, outputLevelMode);
        lcd.setCursor(0,1);
      }
    }
    else if (EXTRotaryButtonCheck()) {
JUMP1:
      Timer2Clear();
      if (tempWaveform != outputWaveform) {
        outputWaveform = tempWaveform;
        EXTDisplayWaveform(outputWaveform);
        DDSSignal(outputWaveform); 
        if (tempWaveform != SQUARE) {
          // new selected waveform is sinus or triangle
          outputLevelMaxVrms = (outputWaveform == SINUS) ? V_RMS_MAX_SIN : V_RMS_MAX_TRI;
          outputLevelMinVrms = (outputWaveform == SINUS) ? V_RMS_MIN_SIN : V_RMS_MIN_TRI;
          if (outputLevelMode != V_P2P && outputLevelMaxVrms < outputLevel) {
            // max Vrms has been reduced (change from SINUS to TRIANGLE)
            outputLevel = outputLevelMaxVrms;
          }
          else if (outputLevelMode != V_P2P && outputLevel < outputLevelMinVrms) {
            outputLevel = outputLevelMinVrms;
          }
          tempLevel = outputLevel;
          setAndStoreOutputLevel();
          EXTDisplayLevel(outputLevel, outputLevelMode);
          if (outputFrequency > MAX_FREQ) {
            // happens when waveform switched from TTL to SINUS/TRIANGLE
            outputFrequency = MAX_FREQ;
            setAndStoreOutputFrequency();
            EXTDisplayFrequency(outputFrequency,0);	
          }
        }
        eeprom_busy_wait();
        eeprom_update_byte(&eWaveform,outputWaveform);
        EXTRelaisOnOff((outputWaveform == SQUARE)?RELAIS_ON:RELAIS_OFF);
        if (inputMode == I_EXPLICIT) EXTBuzzerRing(80);
      }
      lcd.setCursor(0,1);
    } 
    else if (EXTSelectSwitchCheck()) {
      Timer2Clear();
      if (tempWaveform != outputWaveform) EXTDisplayWaveform(outputWaveform);	
      if (outputWaveform != SQUARE) {
        // output level can only be changed for sinus and triangle waveform
        systemState = M_LEVEL;
        tempLevel = outputLevel;
        EXTDisplayLevel(outputLevel, outputLevelMode);
        lcd.setCursor((outputLevelStepSize == V_STEPSIZE_10 ? 11 : 12),1);
        lcd.blink();
      }
      else {
        // square was selected -> TTL level can't be changed
        systemState = M_FREQUENCY1;
        tempFrequency = outputFrequency;
        if (tempFrequency >= 1000000) {
          tempDigit = 100000;
          lcd.setCursor(6,0);
        }
        else {
          tempDigit = 1000;
          lcd.setCursor(8,0);
        }
        lcd.cursor();
        lcd.noBlink();
      }
    }
  }
  else if (systemState == M_LEVEL) {
    // changing output level (sinus & triangle)
    if (systemIdleTime >= MAX_IDLE_TIME) {
      systemState = M_IDLE;
      Timer2Stop();
      lcd.noCursor();
      lcd.noBlink();
      if (tempLevel != outputLevel) EXTDisplayLevel(outputLevel, outputLevelMode);	
    }
    else if ((ret = EXTRotaryImpulseCheck()) != 0) {
      Timer2Clear();
      // tempLevel gets increased or decreased by actual step size
      uint16_t tempLevel2 = tempLevel + (outputLevelStepSize * ret);
      if (tempLevel2 >= ((outputLevelMode == V_P2P) ? OUTPUT_LEVEL_VPP_MIN : outputLevelMinVrms) && 
          tempLevel2 <= ((outputLevelMode == V_P2P) ? OUTPUT_LEVEL_VPP_MAX : outputLevelMaxVrms)) {
        tempLevel = tempLevel2;
      }
      else {
        EXTBuzzerRing(10);
      }
      EXTDisplayLevel(tempLevel, outputLevelMode);
      lcd.setCursor((outputLevelStepSize == V_STEPSIZE_10 ? 11 : 12),1);
      if (inputMode == I_NORMAL && tempLevel != outputLevel) {
        outputLevel = tempLevel;
        setAndStoreOutputLevel();
      }
    }
    else if ((event = EXTRotaryButtonCheck()) != idle) {
      Timer2Clear();
      if (inputMode == I_EXPLICIT && tempLevel != outputLevel) {
        outputLevel = tempLevel;
        setAndStoreOutputLevel();
        EXTBuzzerRing(80);
      }
      else {
        if (event == longPress) {
          // toggle between Vpp & Vrms, output level might slightly change due to rounding & casting
          outputLevelMode = (outputLevelMode == V_RMS) ? V_P2P : V_RMS;
          if (outputLevelMode == V_RMS) {
            // converting output level from Vpp to Vrms
            outputLevel = (uint16_t)(outputLevel / (2 * (double)((outputWaveform == SINUS) ? SQRT2 : SQRT3)));
            if (outputLevelMaxVrms < outputLevel) outputLevel = outputLevelMaxVrms;
            if (outputLevel < outputLevelMinVrms) outputLevel = outputLevelMinVrms;
          }
          else {
            // converting output level from Vrms to Vpp (add 0.8 to minimize conversion errors),
            outputLevel = (uint16_t)((outputLevel * 2 * (double)((outputWaveform == SINUS) ? SQRT2 : SQRT3)) + 0.8);
            if (OUTPUT_LEVEL_VPP_MAX < outputLevel) outputLevel = OUTPUT_LEVEL_VPP_MAX;
            if (outputLevel < OUTPUT_LEVEL_VPP_MIN) outputLevel = OUTPUT_LEVEL_VPP_MIN;
          }
          tempLevel = outputLevel;
          EXTDisplayLevel(outputLevel, outputLevelMode);
          lcd.setCursor((outputLevelStepSize == V_STEPSIZE_10 ? 11 : 12),1);
          setAndStoreOutputLevel();
          eeprom_busy_wait();
          eeprom_update_byte(&eLevelMode,outputLevelMode);
        }
        else {
          // shortPress, we change step size
          outputLevelStepSize = (outputLevelStepSize == V_STEPSIZE_10) ? V_STEPSIZE_SMALL : V_STEPSIZE_10;
          lcd.setCursor((outputLevelStepSize == V_STEPSIZE_10 ? 11 : 12),1);
        }
      }
    }
    else if (EXTSelectSwitchCheck()) {
      systemState = M_FREQUENCY1;
      Timer2Clear();
      if (tempLevel != outputLevel) EXTDisplayLevel(outputLevel, outputLevelMode);	
      tempFrequency = outputFrequency;
      if (tempFrequency >= 1000000) {
        tempDigit = 100000;
        lcd.setCursor(6,0);
      }
      else {
        tempDigit = 1000;
        lcd.setCursor(8,0);
      }
      lcd.cursor();
      lcd.noBlink();
    }
  }
  else if (systemState == M_FREQUENCY1) {
    // changing output frequency (selecting digits)
    if (systemIdleTime >= MAX_IDLE_TIME) {
      systemState = M_IDLE;
      Timer2Stop();
      lcd.noCursor();
      if (outputFrequency == 0) {
        outputFrequency = OUTPUT_FREQU_DEFAULT;
        EXTDisplayFrequency(outputFrequency,0);
        setAndStoreOutputFrequency();
        EXTBuzzerRing(80);
      }
      else if (tempFrequency != outputFrequency) {
        EXTDisplayFrequency(outputFrequency,0);	
      }
    }
    else if ((ret = EXTRotaryImpulseCheck()) != 0) {
      Timer2Clear();
      switch (tempDigit) {
        case 1:
          if (ret == -1) { tempDigit = 10; lcd.setCursor(11,0); }
          break;
        case 10:
          if (ret == -1) { tempDigit = 100; lcd.setCursor(10,0); }
          else { tempDigit = 1; lcd.setCursor(12,0); }
          break;
        case 100:
          if (ret == -1) { tempDigit = 1000; lcd.setCursor(8,0); }
          else { tempDigit = 10; lcd.setCursor(11,0); }
          break;
        case 1000:
          if (ret == -1) { tempDigit = 10000; lcd.setCursor(7,0); }
          else { tempDigit = 100; lcd.setCursor(10,0); }
          break;
        case 10000:
          if (ret == -1) { tempDigit = 100000; lcd.setCursor(6,0); }
          else { tempDigit = 1000; lcd.setCursor(8,0); }
          break;
        case 100000:
          if (ret == 1) { tempDigit = 10000; lcd.setCursor(7,0); }
          break;
        default: break;
      }
    }
    else if (EXTRotaryButtonCheck()) {
      systemState = M_FREQUENCY2;
      Timer2Clear();
      if (tempDigit == 10000) {
        EXTDisplayFrequency(outputFrequency,1);
        lcd.setCursor(7,0);
      }
      else if (tempDigit == 100000) {
        EXTDisplayFrequency(outputFrequency,2);
        lcd.setCursor(6,0);
      }
      lcd.blink();
    }
    else if (EXTSelectSwitchCheck()) {
      systemState = M_WAVEFORM;
      Timer2Clear();
      rotaryImpulseLeft = rotaryImpulseRight = 0;
      if (outputFrequency == 0) {
        outputFrequency = OUTPUT_FREQU_DEFAULT;
        setAndStoreOutputFrequency();
        EXTBuzzerRing(80);
      }
      EXTDisplayFrequency(outputFrequency,0);
      tempWaveform = outputWaveform;
      lcd.setCursor(0,1);
      lcd.blink();
    }
  }
  else if (systemState == M_FREQUENCY2) {
    // changing output frequency (changing digits)
    if (systemIdleTime >= MAX_IDLE_TIME) {
      systemState = M_IDLE;
      Timer2Stop();
      lcd.noCursor();
      if (outputFrequency == 0) {
        outputFrequency = OUTPUT_FREQU_DEFAULT;
        setAndStoreOutputFrequency();
        EXTBuzzerRing(80);
      }
      EXTDisplayFrequency(outputFrequency,0);	
    }
    else if ((ret = EXTRotaryImpulseCheck()) != 0) {
      Timer2Clear();
      if (ret == -1) {
        temp = tempFrequency - tempDigit;
        if (temp >= 0) tempFrequency -= tempDigit;
      }
      else {
        temp = tempFrequency + tempDigit;
        if (temp <= ((outputWaveform==SQUARE)?MAX_FREQ_TTL:MAX_FREQ)) {
          tempFrequency += tempDigit;
        }
      }
      if (tempDigit == 10000) EXTDisplayFrequency(tempFrequency,1);
      else if (tempDigit == 100000) EXTDisplayFrequency(tempFrequency,2);
      else EXTDisplayFrequency(tempFrequency,0);
      lcd.blink();
      switch ( tempDigit ) {
        case 1:
          lcd.setCursor(12,0); break;
        case 10:
          lcd.setCursor(11,0); break;
        case 100:
          lcd.setCursor(10,0); break;
        case 1000:
          lcd.setCursor(8,0); break;
        case 10000:
          lcd.setCursor(7,0); break;
        case 100000:
          lcd.setCursor(6,0); break;
        default: break;
      }
      if (inputMode == I_NORMAL && tempFrequency != outputFrequency) {
        outputFrequency = tempFrequency;
        setAndStoreOutputFrequency();
      }
    }
    else if (EXTRotaryButtonCheck()) {
      systemState = M_FREQUENCY1;
      Timer2Clear();
      if (inputMode == I_EXPLICIT && tempFrequency != outputFrequency) {
        outputFrequency = tempFrequency;
        setAndStoreOutputFrequency();
        EXTBuzzerRing(80);
#ifdef USE_SERIAL
        Serial.printf(F("Frequency: %lu"),outputFrequency);
#endif
      }
      EXTDisplayFrequency(outputFrequency,0);	
      lcd.cursor();
      lcd.noBlink();
      switch ( tempDigit ) {
        case 1:
          lcd.setCursor(12,0); break;
        case 10:
          lcd.setCursor(11,0); break;
        case 100:
          lcd.setCursor(10,0); break;
        case 1000:
          lcd.setCursor(8,0); break;
        case 10000:
          lcd.setCursor(7,0); break;
        case 100000:
          lcd.setCursor(6,0); break;
        default: break;
      }
    }
    else if (EXTSelectSwitchCheck()) {
      systemState = M_WAVEFORM;
      Timer2Clear();
      rotaryImpulseLeft = rotaryImpulseRight = 0;
      if (outputFrequency == 0) {
        outputFrequency = OUTPUT_FREQU_DEFAULT;
        setAndStoreOutputFrequency();
        EXTBuzzerRing(80);
      }
      EXTDisplayFrequency(outputFrequency,0);
      tempWaveform = outputWaveform;
      lcd.setCursor(0,1);
      lcd.blink();
    }
  }
}

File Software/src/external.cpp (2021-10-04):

/*
 * EXTERNAL.CPP: definitions and functions for the AD9833 function generator
 *
 * Created: June 2016
 *          2021/10/01 possibility to set output level in Vrms added
 * Author : ThJ (yellobyte@bluewin.ch)
*/

#include <Arduino.h>
#include <SPI.h>
#include <LiquidCrystal_I2C.h>
#include "ad9833.h"
#include "external.h"

#define PIN_RELAY         PIN_PB0
#define PIN_BUZZER        PIN_PC0
#define PIN_ENCODERA      PIN_PD2
#define PIN_ENCODERB      PIN_PD3
#define PIN_ENCODERBUTTON PIN_PD4
#define PIN_PUSHBUTTON    PIN_PD7
#define PIN_AD5452_CS     PIN_PB1
#define SPI_AD5452        SPISettings(2000000, MSBFIRST, SPI_MODE2)

extern LiquidCrystal_I2C  lcd;
extern uint8_t            outputLevelStepSize;

volatile uint8_t rotaryImpulseLeft = 0;
volatile uint8_t rotaryImpulseRight = 0;

//
// functions for displaying frequency, waveform and output level on 16x2 LCD display
//
void EXTDisplayFrequency(uint32_t frequ, uint8_t leadingZeros)
{
  uint8_t  i;
  uint8_t	 digit[7];
  uint32_t temp;

  temp = (frequ < 10000000) ? frequ : 9999999;
  for (i = 0; i < 7; i++) digit[i] = 0; // clear array
  for (i = 0; temp > 0; i++) {
    digit[6-i] = (uint8_t)(temp % 10);
    temp = temp / 10;
  }
  lcd.setCursor(4,0);
  for (i = 0; i < 7; i++) {
    if (i == 0) {
      if ( digit[0] != 0 ) {
        lcd.print((char)(48+digit[0]));
        lcd.print((char)'.'); 
      }
      else {
         lcd.print((char)' ');
         lcd.print((char)' ');
      }
    }
    else if ( i == 1 && digit[0] == 0 && digit[1] == 0 && !(leadingZeros == 2) ) {
       lcd.print((char)' ');
    }
    else if ( i == 2 && digit[0] == 0 && digit[1] == 0 && digit[2] == 0 && leadingZeros == 0 ) {
       lcd.print((char)' ');
    }
    else if (i == 3) {
      lcd.print((char)(48+digit[i]));
      lcd.print((char)'.'); 
    }
    else {
      lcd.print((char)(48+digit[i])); 
    }
  }
  lcd.print((char)'k');
  lcd.print((char)'H');
  lcd.print((char)'z');
}

void EXTDisplayLevel(uint16_t outputLevel, uint8_t outputLevelMode)
{
  uint8_t  i, digits[3];
  uint16_t temp = outputLevel;

  for (i=0; i<3; i++) digits[i] = 0;
  digits[2] = (uint8_t)(temp % 10);
  temp /= 10;
  digits[1] = (uint8_t)(temp % 10);
  temp /= 10;
  digits[0] = (uint8_t)(temp % 10);
  lcd.setCursor(9,1);
  lcd.print((char)(48+digits[0]));
  lcd.print((char)'.');
  lcd.print((char)(48+digits[1]));
  lcd.print((char)(48+digits[2]));

  lcd.setCursor(13,1);
  lcd.print(outputLevelMode ? "Vpp" : "Vrm");
}

void EXTDisplayWaveform(uint8_t waveform)
{
  switch (waveform){
    case SINUS:
      lcd.setCursor(0,1);
      lcd.print("SINUS   "); 
      break;
    case SQUARE:
      lcd.setCursor(0,1);
      lcd.print("SQUARE    5V-TTL"); 
      break;
    case TRIANGLE:
      lcd.setCursor(0,1);
      lcd.print("TRIANGLE");
      break;
    default:
      break;
  }	
}

//
// functions for handling the relais
//
void EXTRelaisInit(void)
{
  pinMode(PIN_RELAY, OUTPUT);   
  digitalWrite(PIN_RELAY, LOW);     // relais off
}

void EXTRelaisOnOff(uint8_t setting)
{
  if ( setting == RELAIS_ON )
    digitalWrite(PIN_RELAY, HIGH);  // relais on
  else
    digitalWrite(PIN_RELAY, LOW);   // relais off
}

//
// functions for handling the buzzer
//
void EXTBuzzerInit(void)
{
  pinMode(PIN_BUZZER, OUTPUT);   
  digitalWrite(PIN_BUZZER, LOW);   // buzzer off
}

void EXTBuzzerRing(uint16_t ms)
{
  digitalWrite(PIN_BUZZER, HIGH);  // buzzer on
  delay(ms);					             // Buzzer x ms aktiv
  digitalWrite(PIN_BUZZER, LOW);   // buzzer off
}

//
// functions for handling the select button
//
void EXTSelectSwitchInit(void)
{
  pinMode(PIN_PUSHBUTTON, INPUT_PULLUP);   
}

uint8_t EXTSelectSwitchCheck(void)
{
  // function returns: 1...button was pressed, 0...otherwise
  static uint8_t oldStatus = 1;                         // default - switch not pressed
  uint8_t	status, ret = 0;
 
  status = digitalRead(PIN_PUSHBUTTON);
  if (!status && oldStatus) {                           // any input change ?
    for (uint8_t n = 0; n < 5; ) {
      delayMicroseconds(200);
      n = !digitalRead(PIN_PUSHBUTTON) ? n + 1 : 0;
    }
    // since 5 * 200us = 1ms no change at input
    ret = 1;
    oldStatus = status;                                 // remember last stable signal
  }
  else {
    oldStatus = status;                                 // remember last reading
  }  
  return(ret);
}

//
// functions handling the rotary encoder & button
//
static void impulsIrq()
{
  // PIN_ENCODERB==1 -> left turn,  PIN_ENCODERB==0 -> right turn
  if (digitalRead(PIN_ENCODERB)) {
    rotaryImpulseLeft++;
  }
  else {
    rotaryImpulseRight++;
  }
  // trailing spikes will be ignored for some time
  delayMicroseconds(50);
}

void EXTRotaryInit(void)
{
  pinMode(PIN_ENCODERBUTTON, INPUT_PULLUP);
  pinMode(PIN_ENCODERB, INPUT_PULLUP);
  pinMode(PIN_ENCODERA, INPUT_PULLUP);
  attachInterrupt(digitalPinToInterrupt(PIN_ENCODERA),impulsIrq,FALLING);
}

buttonEvent EXTRotaryButtonCheck(void)
{
  // function returns: 1...short press (<0.5s), 2...long press (>0.5s-3s), 0...otherwise
  static uint8_t oldStatus = 1;                             // default - button not pressed
  uint8_t	status;
  buttonEvent event = idle;
 
  status = digitalRead(PIN_ENCODERBUTTON);
  if (!status && oldStatus) {                               // falling edge ?
    for (uint8_t n = 0; n < 5; ) {                          // wait for stable low
      delayMicroseconds(200);
      n = !digitalRead(PIN_ENCODERBUTTON) ? n + 1 : 0;
    }
    for (uint16_t n = 1; status == LOW && n < 50; ) {       // wait for rising edge
      delay(100);
      if (!(status = digitalRead(PIN_ENCODERBUTTON))) n++;  // input still low -> knob still pressed
      else event = (n < 5) ? shortPress : longPress;        // input high again -> knob was released
    }
    oldStatus = status;                                     // remember last stable signal
  }
  else {
    oldStatus = status;                                     // remember last reading
  }
  return(event);
}

int8_t EXTRotaryImpulseCheck(void)
{
  // function returns: -1...knob was turned left, 1...knob was turned right, 0...knob was idle
  uint8_t ret = 0;
  if (rotaryImpulseLeft) {
    ret = -1;
    rotaryImpulseLeft--;
  }
  else if (rotaryImpulseRight) {
    ret = 1;
    rotaryImpulseRight--;
  }
  return(ret);
}

//
// functions handling the DAC AD5452 for setting output voltage level when SINUS or TRIANGLE
// (the DAC R-2R ladder is used to set the amplification ratio of OpAmp IC6, the output level range
// is +/- 3V (6Vpp) at maximum, adjusted with R11 at BNC output)
//
void EXTDacInit(void)
{
  SPI.begin();
}
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
